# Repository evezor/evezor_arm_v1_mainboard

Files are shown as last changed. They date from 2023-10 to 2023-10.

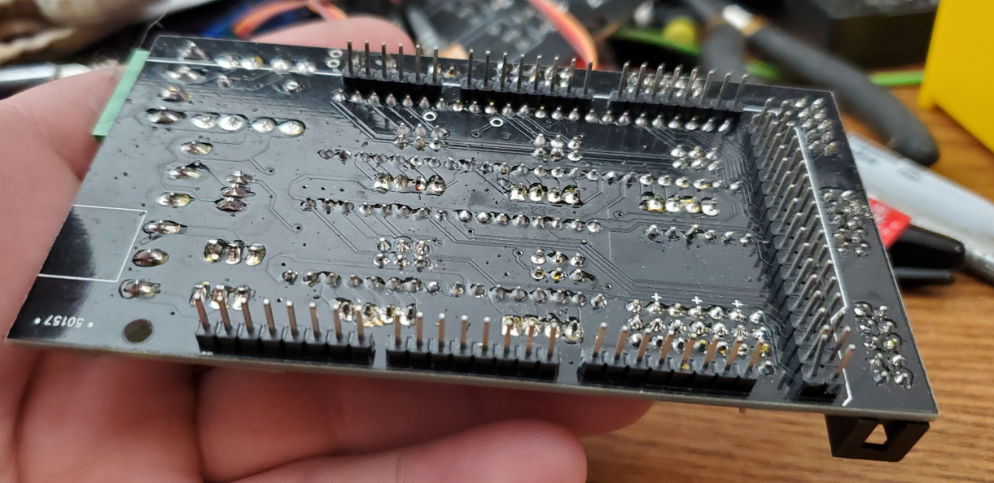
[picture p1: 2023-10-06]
pics/sm2.PNG

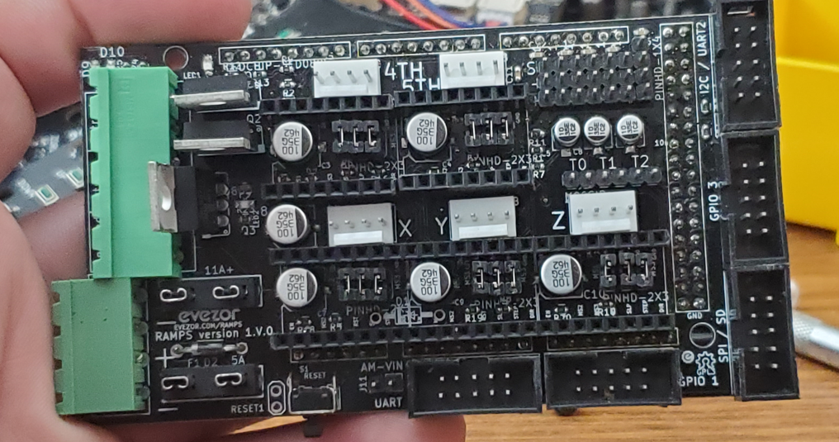
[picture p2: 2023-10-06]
pics/sm.PNG

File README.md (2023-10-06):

# evezor_arm_v1_mainboard_v1

This baord is based on the RAMPS1.4 Board https://reprap.org/wiki/RAMPS_1.4

The motor connectors have been changed to Molex KK connectors and the extra pins are broken out in the Gadgeteer Standard pinout

Source files can be found here: https://github.com/evezor/evezor_arm_v1_mainboard_V1

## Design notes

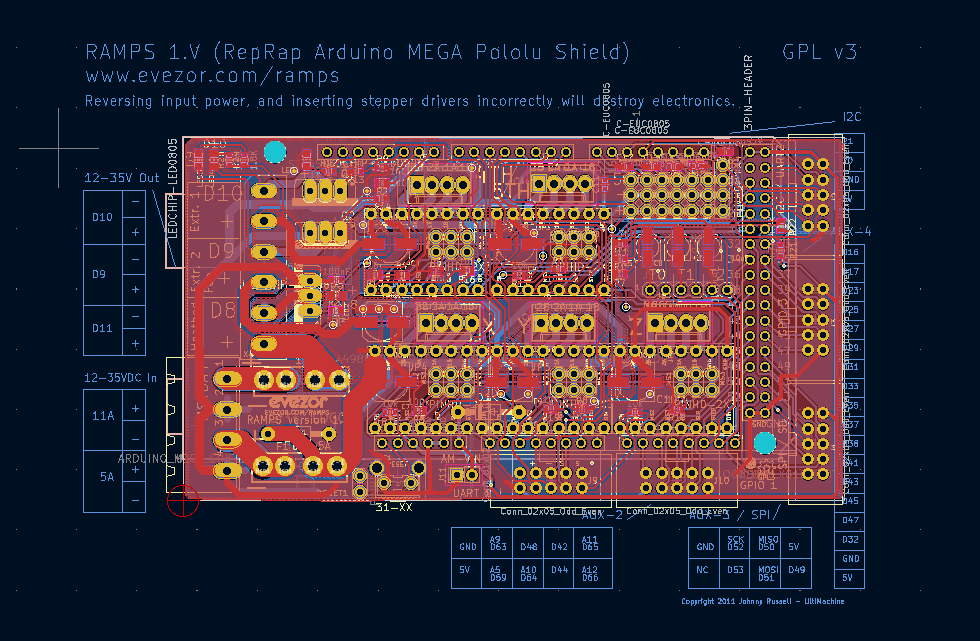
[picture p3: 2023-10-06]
pics/copper.PNG

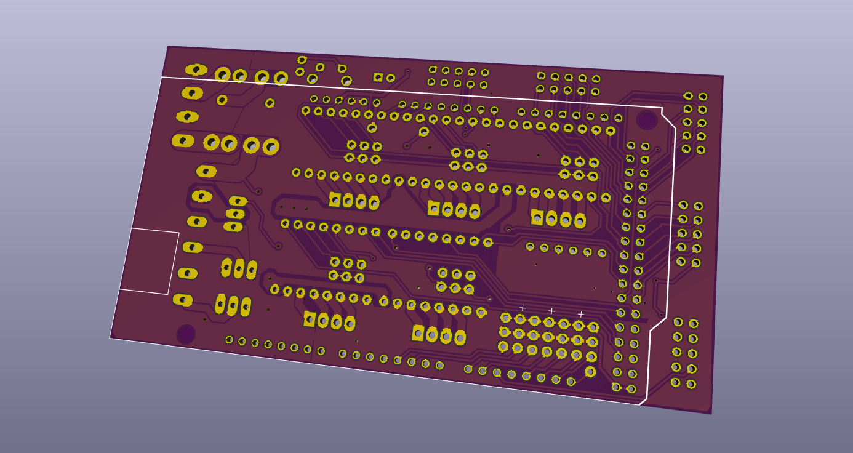
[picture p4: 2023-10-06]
pics/back.PNG

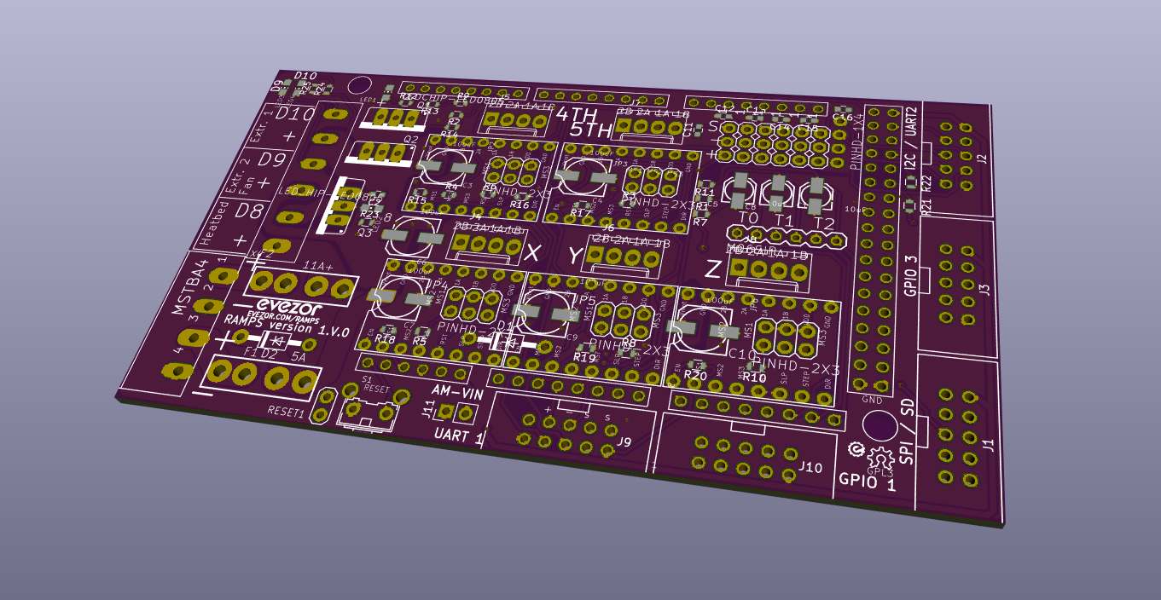
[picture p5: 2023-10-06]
pics/front.PNG

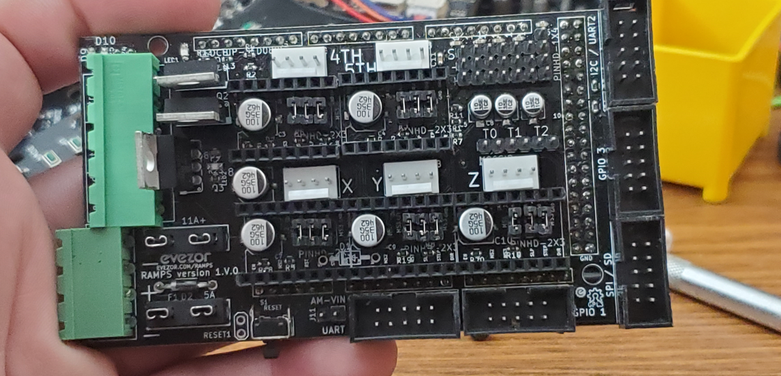
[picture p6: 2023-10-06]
cad_files/sm.PNG

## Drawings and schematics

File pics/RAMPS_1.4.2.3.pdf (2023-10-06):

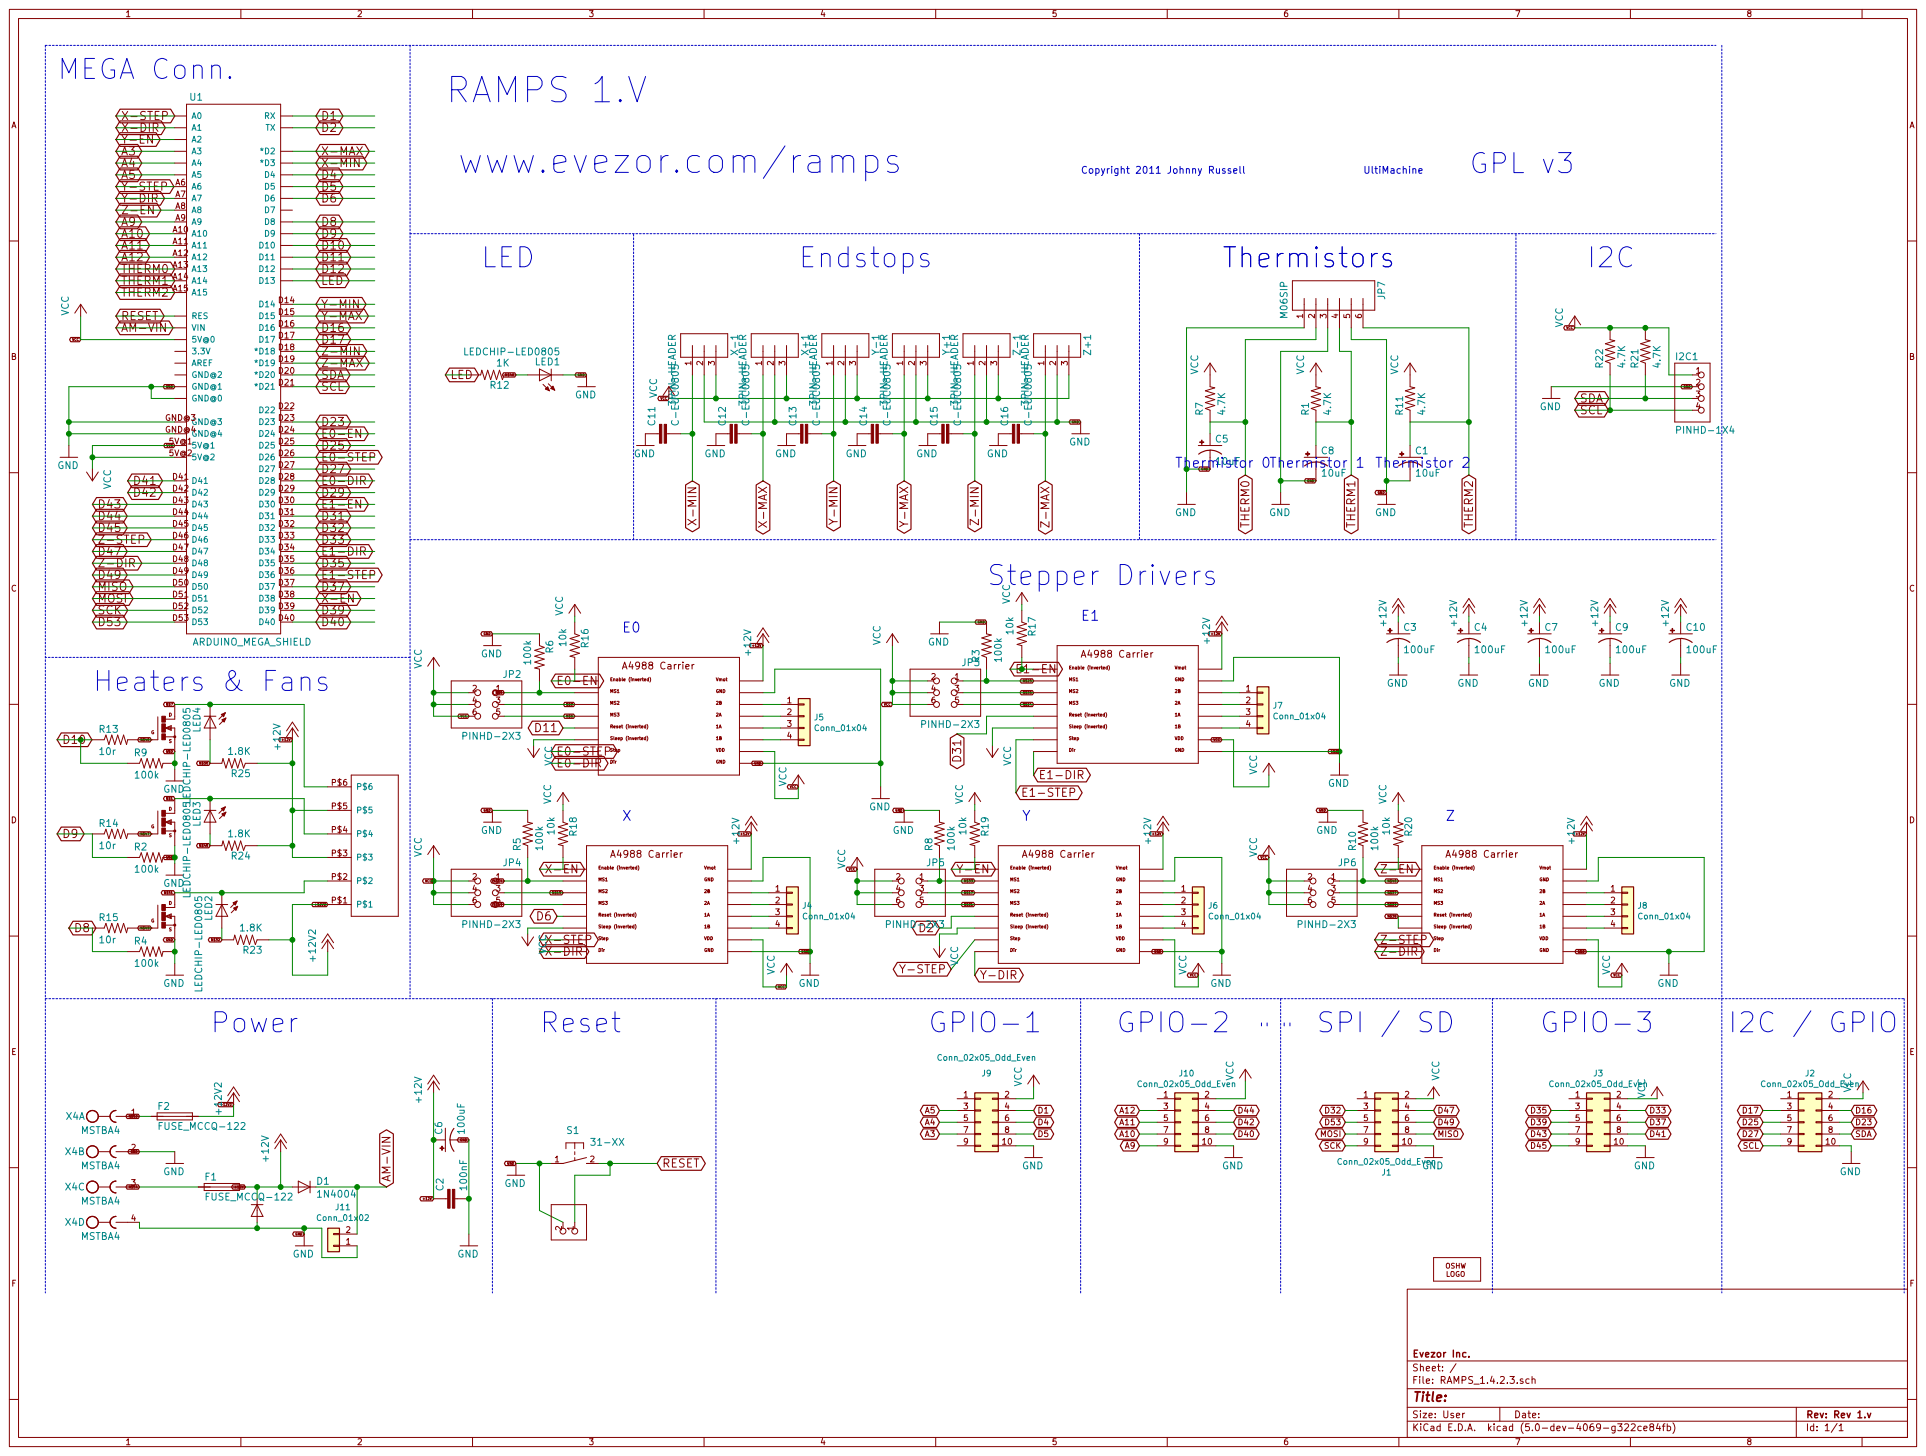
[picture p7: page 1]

www.evezor.com/ramps

3 X+1 3PIN-HEADER GND +12V GND VCC +12V

1 C11 C-EUC0805 C12 C-EUC0805 C13 C-EUC0805 C14 C-EUC0805 C15 C-EUC0805 C16 C-EUC0805 GND GND GND GND GND GND E0

File: RAMPS_1.4.2.3.sch Sheet: / Evezor Inc.

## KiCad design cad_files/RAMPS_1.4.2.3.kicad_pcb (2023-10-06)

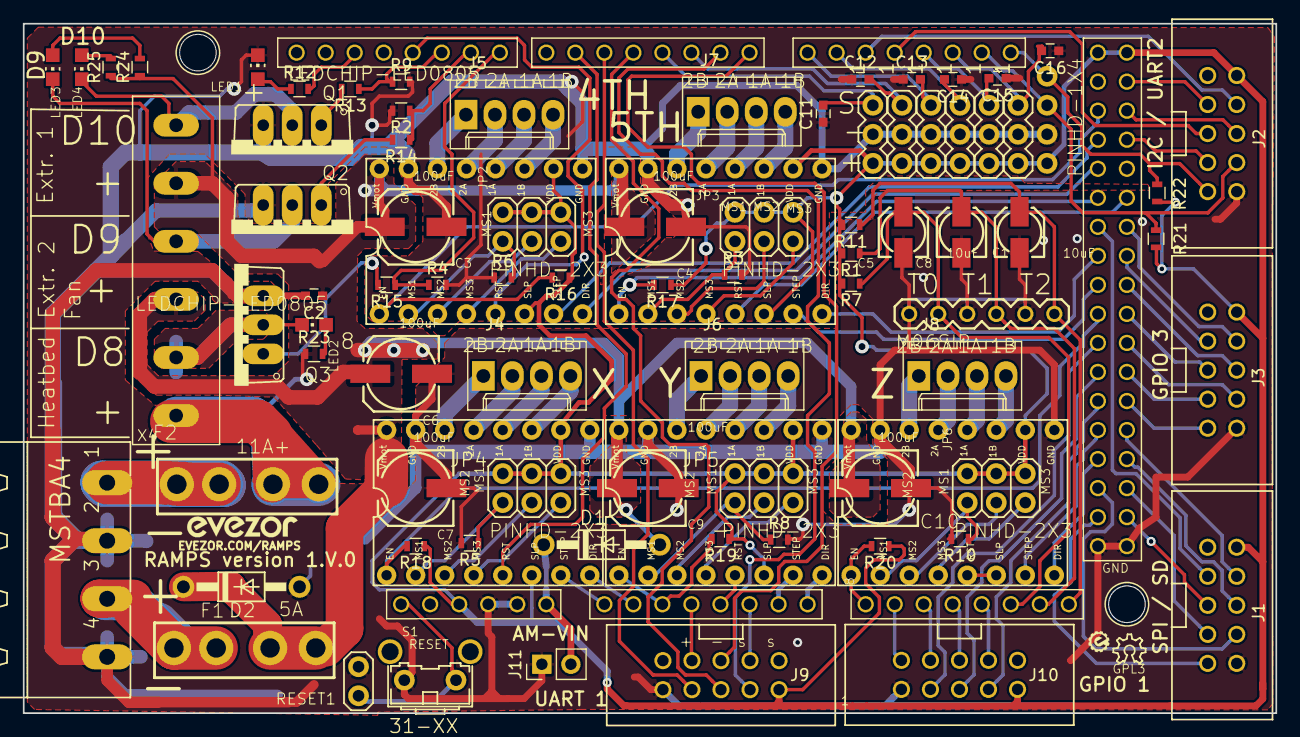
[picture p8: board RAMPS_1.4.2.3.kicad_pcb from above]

Board: 2 copper layers, 109.6 x 60.3 mm, 87 parts (0 on the bottom side), 119 nets.

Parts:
C1, C5, C8: 10uF; 153CLV-0405
C2: 100nF; C_0603
C3, C4, C6, C7, C9, C10: 100uF; 153CLV-0605
C11, C12, C13, C14, C15, C16: C-EUC0805; C_0603
D1, D2: 1N4004; DO41-10
F1, F2: FUSE_MCCQ-122
I2C1: PINHD-1X4; 1X04
J1, J2, J3, J9, J10: Conn_02x05_Odd_Even; 10_PIN_IDC
J4, J5, J6, J7, J8: Conn_01x04; Molex_KK-6410-04_04x2.54mm_Straight
J11: Conn_01x02; Pin_Header_Straight_1x02_Pitch2.54mm
JP2, JP3, JP4, JP5, JP6: PINHD-2X3; 2X03
JP7: M06SIP; 1X06
LED1, LED2, LED3, LED4: LEDCHIP-LED0805; CHIP-LED0805
LOGO1: OSHW_LOGO_6MILX0100-NT; OSHW_6X100_NOTEXT
Q1, Q2, Q3: STP55NF06L; TO220BV
R1, R7, R11, R21, R22: 4.7K; R_0603
R2, R3, R4, R5, R6, R8, R9, R10: 100k; R_0603
R12: 1K; R_0603
R13, R14, R15: 10r; R_0603
R16, R17, R18, R19, R20: 10k; R_0603
R23, R24, R25: 1.8K; R_0603
RESET1: PINHD-2
S1: 31-XX; B3F-31XX
U1: ARDUINO_MEGA_SHIELD
U$2: 282837-6
U$4, U$5, U$6, U$7, U$8: A4988BREAKOUT
X4: MSTBA4
X+1: 3PIN-HEADER
X-1: 3PIN-HEADER
Y+1: 3PIN-HEADER
Y-1: 3PIN-HEADER
Z+1: 3PIN-HEADER
Z-1: 3PIN-HEADER

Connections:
+12V: C2.1, C3.+, C4.+, C6.+, C7.+, C9.+, C10.+, D1.A, D2.C, F1.2-1, F1.2-2, F2.2-1, F2.2-2, R23.1, R24.1, R25.1, U$2.P$1, U$2.P$3, U$2.P$5, U$4.VMOT, U$5.VMOT, U$6.VMOT, U$7.VMOT, U$8.VMOT
A3: J9.7, U1.A3
A4: U1.A4, U$7.RST
A5: J9.3, U1.A5
A9: J10.9, U1.A9
A10: J10.7, U1.A10
A11: J10.5, U1.A11
A12: J10.3, U1.A12
AM-VIN: D1.C, J11.2, U1.VIN
D1: J9.5, U1.RX
D2: J9.4, U1.TX
D4: J9.6, U1.D4
D5: J9.8, U1.D5
D6: U1.D6, U$6.RST
D8: R4.1, R15.1, U1.D8
D9: R2.1, R14.1, U1.D9
D10: R9.1, R13.1, U1.D10
D11: U1.D11, U$4.RST
D16: J2.4, U1.D16
D17: J2.5, U1.D17
D23: J2.3, U1.D23
D25: J2.6, U1.D25
D27: J2.7, U1.D27
D31: U1.D31, U$5.RST
D32: J1.3, U1.D32
D33: J3.4, U1.D33
D35: J3.3, U1.D35
D37: J3.6, U1.D37
D39: J3.5, U1.D39
D40: J10.8, U1.D40
D41: J3.8, U1.D41
D42: J10.6, U1.D42
D43: J3.7, U1.D43
D44: J10.4, U1.D44
D45: J3.9, U1.D45
D47: J1.4, U1.D47
D49: J1.6, U1.D49
D53: J1.5, U1.D53
E0-DIR: U1.D28, U$4.DIR
E0-EN: R16.2, U1.D24, U$4.EN
E0-STEP: U1.D26, U$4.STEP
E1-DIR: U1.D34, U$5.DIR
E1-EN: R17.2, U1.D30, U$5.EN
E1-STEP: U1.D36, U$5.STEP
GND: C1.-, C2.2, C3.-, C4.-, C5.-, C6.-, C7.-, C8.-, C9.-, C10.-, C11.1, C12.1, C13.1, C14.1, C15.1, C16.1, D2.A, I2C1.2, J1.10, J2.10, J3.10, J9.10, J10.10, J11.1, JP7.1, JP7.3, JP7.5, LED1.C, Q1.S, Q2.S, Q3.S, R2.2, R3.2, R4.2, R5.2, R6.1, R8.2, R9.2, R10.2, RESET1.2, S1.1, U1.GND@0, U1.GND@1, U1.GND@3, U1.GND@4, U$4.GND, U$4.GND@0, U$5.GND, U$5.GND@0, U$6.GND, U$6.GND@0, U$7.GND, U$7.GND@0, U$8.GND, U$8.GND@0, X4.2, X4.4, X+1.2, X-1.2, Y+1.2, Y-1.2, Z+1.2, Z-1.2
LED: R12.2, U1.D13
MISO: J1.8, U1.D50
MOSI: J1.7, U1.D51
unnamed: LED3.C, Q2.D, U$2.P$4
unnamed: JP2.1, R6.2, U$4.MS1
unnamed: JP2.5, U$4.MS3
unnamed: LED4.C, Q1.D, U$2.P$6
unnamed: JP2.3, U$4.MS2
unnamed: JP4.1, R5.1, U$6.MS1
unnamed: JP4.3, U$6.MS2
unnamed: JP5.3, U$7.MS2
unnamed: JP4.5, U$6.MS3
unnamed: JP3.1, R3.1, U$5.MS1
unnamed: JP5.5, U$7.MS3
unnamed: LED2.A, R23.2
unnamed: JP5.1, R8.1, U$7.MS1
unnamed: JP3.5, U$5.MS3
unnamed: JP3.3, U$5.MS2
unnamed: JP6.3, U$8.MS2
unnamed: U$8.RST, U$8.SLP
unnamed: JP6.5, U$8.MS3
unnamed: JP6.1, R10.1, U$8.MS1
unnamed: LED3.A, R24.2
unnamed: LED1.A, R12.1
unnamed: Q2.G, R14.2
unnamed: Q1.G, R13.2
unnamed: Q3.G, R15.2
unnamed: LED4.A, R25.2
unnamed: LED2.C, Q3.D, U$2.P$2
unnamed: F2.1-1, F2.1-2, X4.1
unnamed: F1.1-1, F1.1-2, X4.3
unnamed: J4.1, U$6.2B
unnamed: J4.2, U$6.2A
unnamed: J4.3, U$6.1A
unnamed: J4.4, U$6.1B
unnamed: J5.1, U$4.2B
unnamed: J5.2, U$4.2A
unnamed: J5.3, U$4.1A
unnamed: J5.4, U$4.1B
unnamed: J6.1, U$7.2B
unnamed: J6.2, U$7.2A
unnamed: J6.3, U$7.1A
unnamed: J6.4, U$7.1B
unnamed: J7.1, U$5.2B
unnamed: J7.2, U$5.2A
unnamed: J7.3, U$5.1A
unnamed: J7.4, U$5.1B
unnamed: J8.1, U$8.2B
unnamed: J8.2, U$8.2A
unnamed: J8.3, U$8.1A
unnamed: J8.4, U$8.1B
RESET: RESET1.1, S1.2, U1.RES
SCK: J1.9, U1.D52
SCL: I2C1.4, J2.9, R22.1, U1.D21
SDA: I2C1.3, J2.8, R21.1, U1.D20
THERM0: C5.+, JP7.2, R7.1, U1.A13
THERM1: C8.+, JP7.4, R1.1, U1.A14
THERM2: C1.+, JP7.6, R11.1, U1.A15
VCC: I2C1.1, J1.2, J2.2, J3.2, J9.2, J10.2, JP2.2, JP2.4, JP2.6, JP3.2, JP3.4, JP3.6, JP4.2, JP4.4, JP4.6, JP5.2, JP5.4, JP5.6, JP6.2, JP6.4, JP6.6, R1.2, R7.2, R11.2, R16.1, R17.1, R18.1, R19.1, R20.1, R21.2, R22.2, U1.5V@0, U1.5V@1, U1.5V@2, U$4.SLP, U$4.VDD, U$5.SLP, U$5.VDD, U$6.SLP, U$6.VDD, U$7.SLP, U$7.VDD, U$8.VDD, X+1.3, X-1.3, Y+1.3, Y-1.3, Z+1.3, Z-1.3
X-DIR: U1.A1, U$6.DIR
X-EN: R18.2, U1.D38, U$6.EN
X-MAX: C12.2, U1.D2, X+1.1
X-MIN: C11.2, U1.D3, X-1.1
X-STEP: U1.A0, U$6.STEP
Y-DIR: U1.A7, U$7.DIR
Y-EN: R19.2, U1.A2, U$7.EN
Y-MAX: C14.2, U1.D15, Y+1.1
Y-MIN: C13.2, U1.D14, Y-1.1
Y-STEP: U1.A6, U$7.STEP
Z-DIR: U1.D48, U$8.DIR
Z-EN: R20.2, U1.A8, U$8.EN
Z-MAX: C16.2, U1.D19, Z+1.1
Z-MIN: C15.2, U1.D18, Z-1.1
Z-STEP: U1.D46, U$8.STEP

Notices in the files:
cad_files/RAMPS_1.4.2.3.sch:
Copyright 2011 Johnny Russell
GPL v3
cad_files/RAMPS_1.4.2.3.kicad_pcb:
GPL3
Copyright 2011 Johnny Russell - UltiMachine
